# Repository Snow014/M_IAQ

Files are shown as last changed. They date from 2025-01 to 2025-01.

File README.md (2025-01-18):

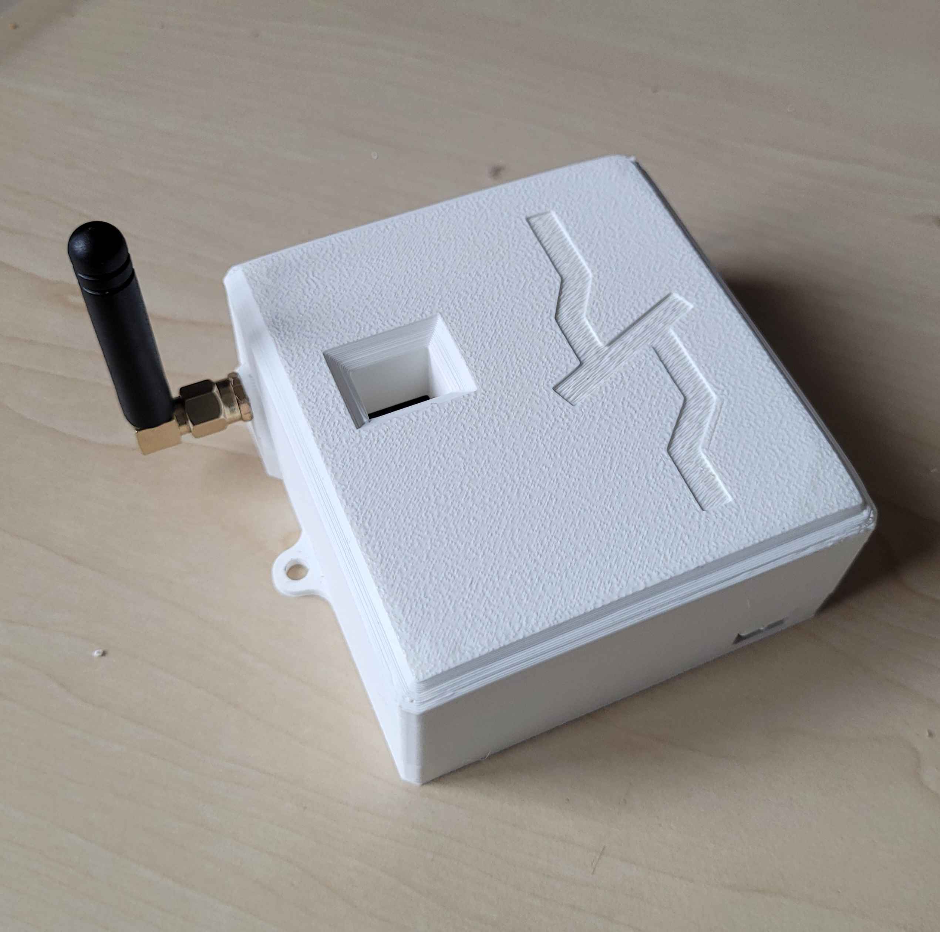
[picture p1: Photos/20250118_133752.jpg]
Side


# M_IAQ

Here you'll find the files for my homemade Internal Air Quality sensor! It uses a custom PCB designed by me, as well as a SEN55 sensor, and a MHZ19C sensor. You can find the full list of meassured data below. The PCB is designed around the Xiao seeeduino ESP32c3, but something like a supermini will also work, though you'll have to adjust the pinouts in code. Keep in mind that I only accounted for the strapping pins of the Xiao esp32c3.

There are four buttons on top, useful for for example switching what data the OLED shows, or forcing the device to calibrate, or shutting down the sensors. These buttons are connected to boot pins, so they do not have pullup resistors in hardware.
The PCB also has an optional header for an OLED screen, to show data right on the device. I designed the board to be powered over the esp's USB port, trough the 5v pin. There is also the option of soldering on a micro-usb connector on the left as power input. The connector has the data lines shorted so most adaptors will give it up to 5W. If this causes issues, you can break the trace between the solder pads near the connector, and they'll be floating. 

## This sensor collects:
* ( True ) Co2, up to 2000ppm
* VoC
* Relative NoX
* particulate matter:
    * PM10
    * PM4
    * PM2.5
    * PM1

## optional features:
* Seperate micro-USB connector on the side for power ( data lines are not hooked up )
* Headers broken out for OLED screen, MHZ19C analog out, and MHZ19C PWM out. You could also hook up a more accurate temperature sensor to this header.

The SEN55 also has an internal temperature and humidity sensor, but especially the temperature sensor is really not that accurate. You can still use it if you want to. 

I have the SEN55 mounted with some strong double sided tape, and the MHZ19C is mounted with zipties. Feel free to make a more elegant solution for this. The Co2 analog and PWM outputs are also broken out as seperate headers, but are not connected to the esp32 on the pcb. 

The SMD headers on the underside are marked to show what sensor connector goes where, and there is a star near the header that connects to pin 1 of the sensor. For the MHZ19C that's the HD pin, for the SEN55 that's 5v. **Be sure to check how the pins connect, and connect them in the right orientation!**

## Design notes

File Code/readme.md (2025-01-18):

This is an example script I wrote, to push all the data from the sensor to a MQTT broker over wifi.

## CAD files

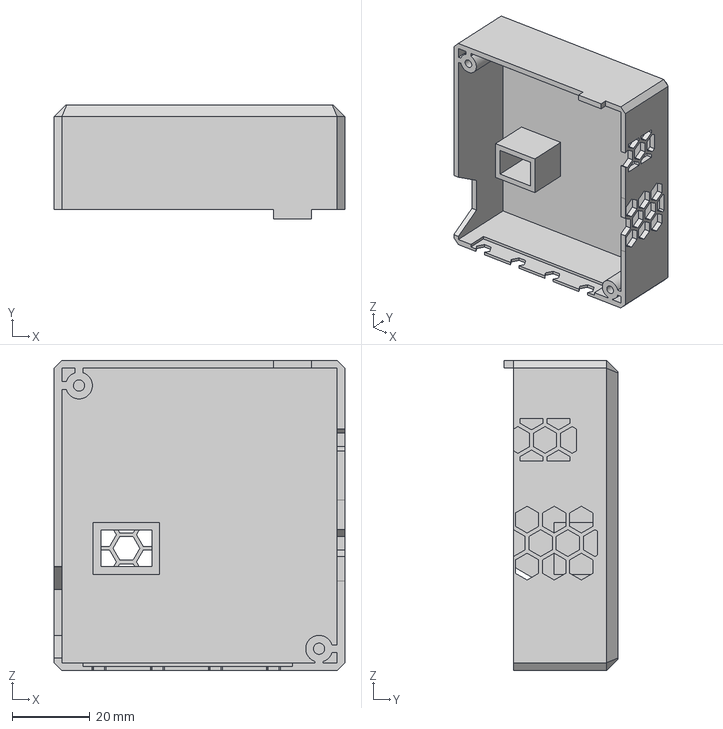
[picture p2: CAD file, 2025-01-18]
Models/Case/Lid.step
75.0 x 29.5 x 80.0 mm

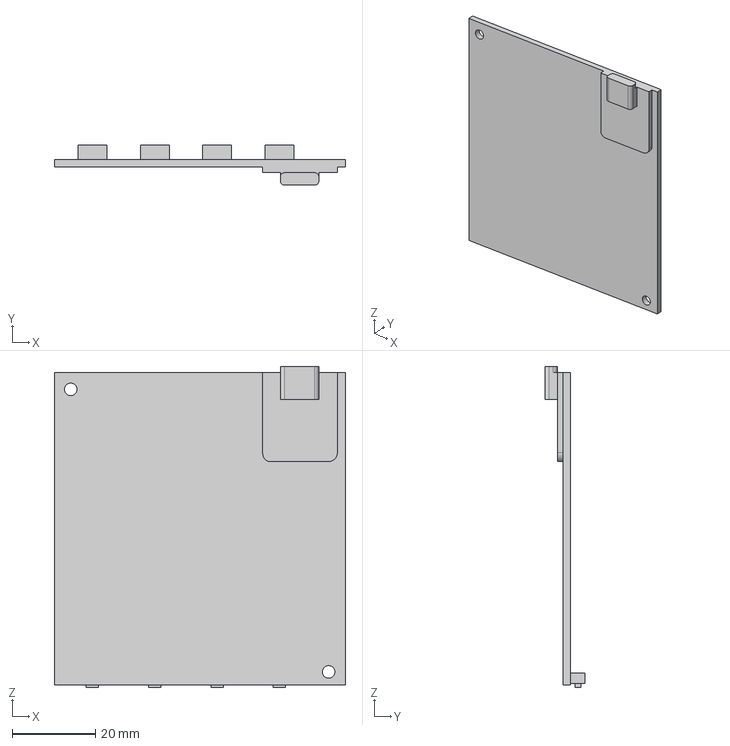
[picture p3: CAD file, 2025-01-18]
Models/components/PCB.step
70.0 x 9.70 x 77.1 mm

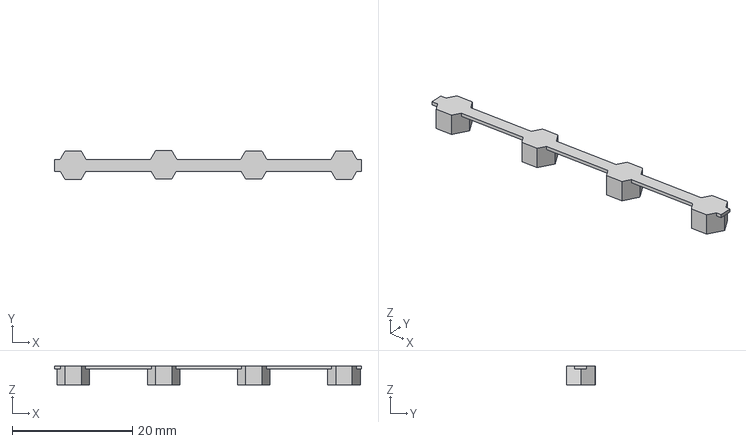
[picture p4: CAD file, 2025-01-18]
Models/Case/Buttons.step
51.0 x 4.76 x 3.10 mm

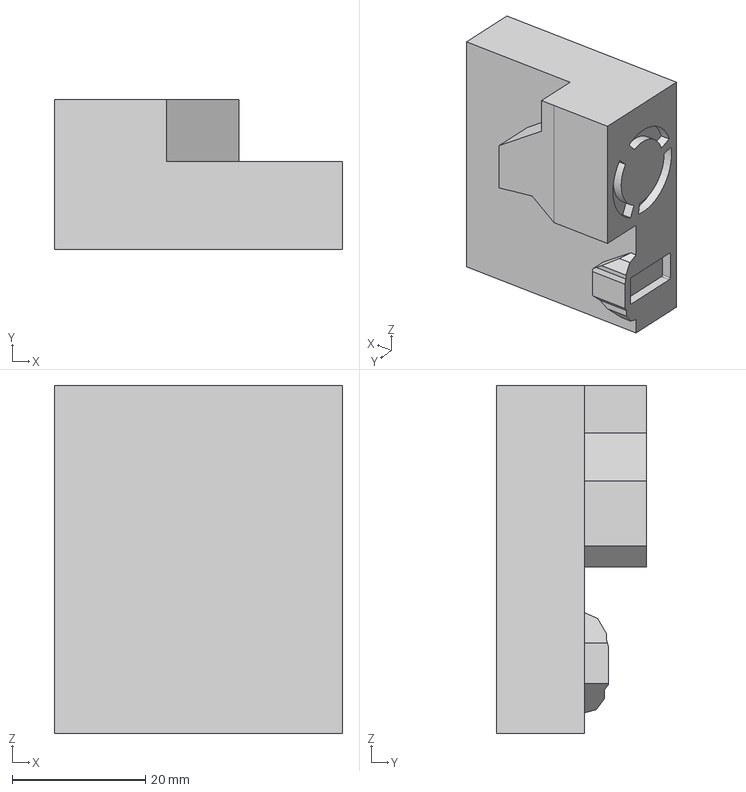
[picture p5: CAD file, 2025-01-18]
Models/components/SEN55 v3.step
43.3 x 22.5 x 52.3 mm

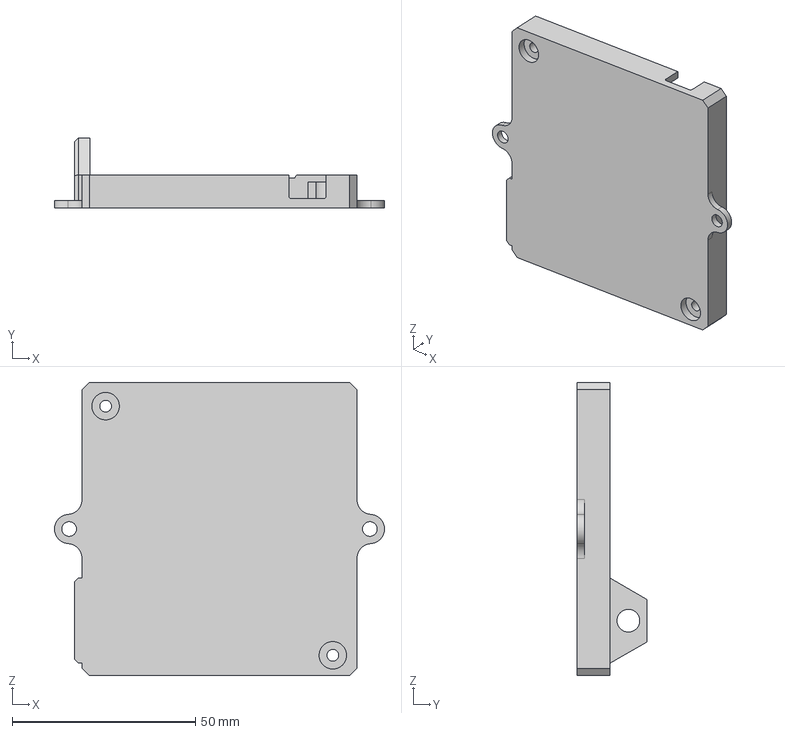
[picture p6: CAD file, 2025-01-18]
Models/Case/Base.step
90.0 x 19.1 x 80.0 mm

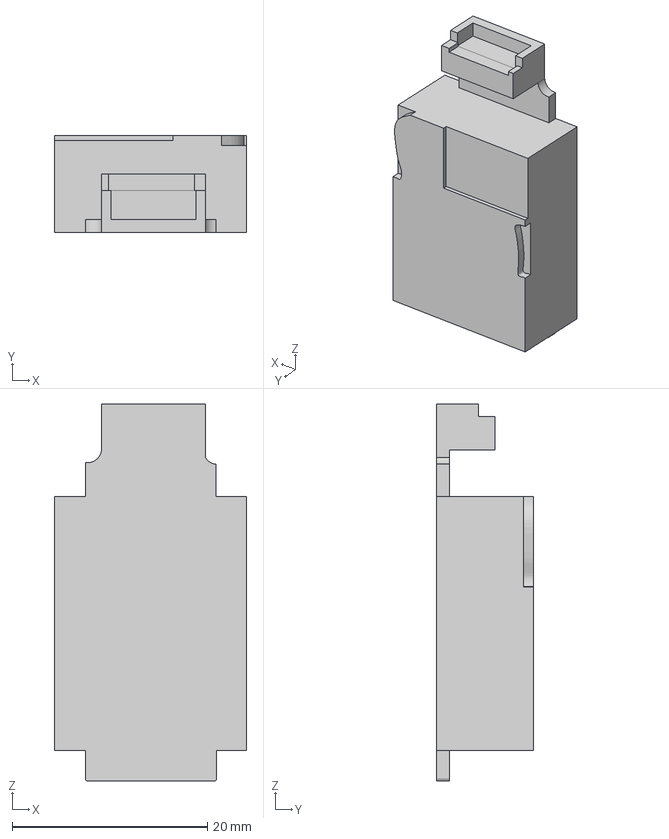
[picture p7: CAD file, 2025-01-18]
Models/components/MHZ-19C.step
19.7 x 9.90 x 38.7 mm

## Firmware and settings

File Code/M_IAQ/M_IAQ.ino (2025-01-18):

#include <WiFi.h>
#include <MQTT.h>

WiFiClient net;
MQTTClient client;

const String WIFI_SSID = "Network name";
const String WIFI_PASS = "Network password";

const char IPBroker[] = "MQTT broker IP";
int Port = 1883;

const char mqttClientId[] = "MQTT client ID";
const char mqttUsername[] = "MQTT broker username";
const char mqttPassword[] = "MQTT broker password";

#include <SensirionI2CSen5x.h>
#include <Wire.h>

SensirionI2CSen5x sen5x;

#include <MHZ19.h>

MHZ19 mhz(&Serial1);

unsigned long lastMeasurement = 0;
unsigned long measureInterval = 30000;  //  30 seconds

void setup(){
  Serial.begin(115200);
  Serial1.begin(9600, SERIAL_8N1, D2, D1);  //  MHZ19C port

  Wire.begin();
  sen5x.begin(Wire);
  if(sen5x.deviceReset() != 0){
    Serial.println("Failed to start SEN55!");
  }
  sen5x.startMeasurement();
}

void loop(){

  connect();
  
  if(millis() - lastMeasurement > measureInterval){
    lastMeasurement = millis();

    //  publish Co2 reading
    MHZ19_RESULT response = mhz.retrieveData();
    if (response == MHZ19_RESULT_OK){
      String co2String = String(mhz.getCO2());

      connect();
      client.publish("CO2", co2String, false, 1);
    }
    else{
      Serial.print(F("Error, code: "));
      Serial.println(response);
    }

    float pm1p0;
    float pm2p5;
    float pm4p0;
    float pm10p0;
    float humidity;
    float temperature;
    float vocIndex;
    float noxIndex;

    bool datardy = false;
    
    // sen5x.startMeasurement();

    // while(!datardy){
    //   sen5x.readDataReady(datardy);
    //   Serial.println("waiting for SEN55..");
    //   delay(100);
    // }

    // delay(2500);

    Serial.println("sending SEN55 data..");

    uint16_t error = sen5x.readMeasuredValues(pm1p0, pm2p5, pm4p0, pm10p0, humidity, temperature, vocIndex, noxIndex);
    Serial.println("VoC: " + String(vocIndex));

    if (error) {
        Serial.print("Error trying to execute readMeasuredValues()");
    } else {
      connect();
      client.publish("PM1P0", String(pm1p0), false, 1);
      delay(50);
      client.publish("PM2P5", String(pm2p5), false, 1);
      delay(50);
      client.publish("PM4P0", String(pm4p0), false, 1);
      delay(50);
      client.publish("PM10P0", String(pm10p0), false, 1);
      delay(50);

      client.publish("VOC", String(vocIndex), false, 1);
      delay(50);
      client.publish("NOX", String(noxIndex), false, 1);
      delay(50);

      client.publish("TEMP_I", String(humidity), false, 1);
      delay(50);
      client.publish("HUM_I", String(temperature), false, 1);
      delay(50);

      //  sen5x.stopMeasurement();
    }
  }
}

void connect(){
  
  if(WiFi.status() != WL_CONNECTED){
    Serial.println("Connecting to " + WIFI_SSID + "..");

    WiFi.mode(WIFI_STA);
    WiFi.begin(WIFI_SSID, WIFI_PASS);

    int tries = 0;

    while (WiFi.status() != WL_CONNECTED){
      //  hopefully fix the wifi connection loop?
      if(tries > 200){
        Serial.println("Couldn't connect to wifi, restarting ESP..");
        ESP.restart();
      }
      Serial.println(String(tries) + "/200..");
      tries++;
      delay(200); 
    }
    Serial.println("Wifi connected!");
  }
  
  if(!client.connected()){
    Serial.println("Connecting to " + String(IPBroker) + "..");

    client.begin(IPBroker, Port, net);
    while (!client.connect(mqttClientId, mqttUsername, mqttPassword)) {
      Serial.print(".");
      delay(200);
    }

    client.onMessage(messageReceived);
    Serial.println("Connected to" + String(IPBroker) + "!");
  }

  WiFi.setSleep(false);
}

void messageReceived(String &topic, String &payload){
  Serial.print(topic);
  Serial.println(payload);
}

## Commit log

2025-01-18 add PCB gerbers
2025-01-18 Add 3d files
    [Base.step, Buttons.step, Lid.step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]
